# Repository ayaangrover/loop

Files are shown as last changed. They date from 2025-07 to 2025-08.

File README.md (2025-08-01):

<div align="center">

# Loop: Compact MP3 Player

</div>

Loop is a compact MP3 player that's designed to be simple and portable.

loop

## Features

- Can play and store up to 10,000 MP3 files from a microSD card
- 3.5mm TRRS headphone jack
- (Optional) speaker support
- Dual playback support(both headphones and speaker)
- USB-C charging
- 8-10 hours of battery life
- Physical buttons for control
- Custom 3D-printed case (magnet and screw versions)

## Parts List

| Component | Source | Price |
|---|---|---|
| DFPlayer | Amazon | $10.00  |
| TP4056 | AliExpress | $2.00 |
| M2 Screws | Aliexpress | $2.00 |
| M2 Heatset Inserts  | Aliexpress | $2.00 |
| LiPo Battery | Amazon (900mAh) | $8.00 |
| Audio Jack | LCSC | $11.50  |
| Buttons (x3) | LCSC | $0.60 |
| Resistors | LCSC | $1.41 |
| Speaker (x2) | Aliexpress | $1.90 |
| PCB | JLCPCB | $31.00  |
| Case | Printed via Hack Club #printing-legion | Free |
| MicroSD Card | Aliexpress | $3.00 |
| **Total** | — | **$73.41** |

## Enclosure

Designed in Fusion 360. Available in ```./case```.

case

## Firmware

No firmware needed! DFPlayer handles all the playing.

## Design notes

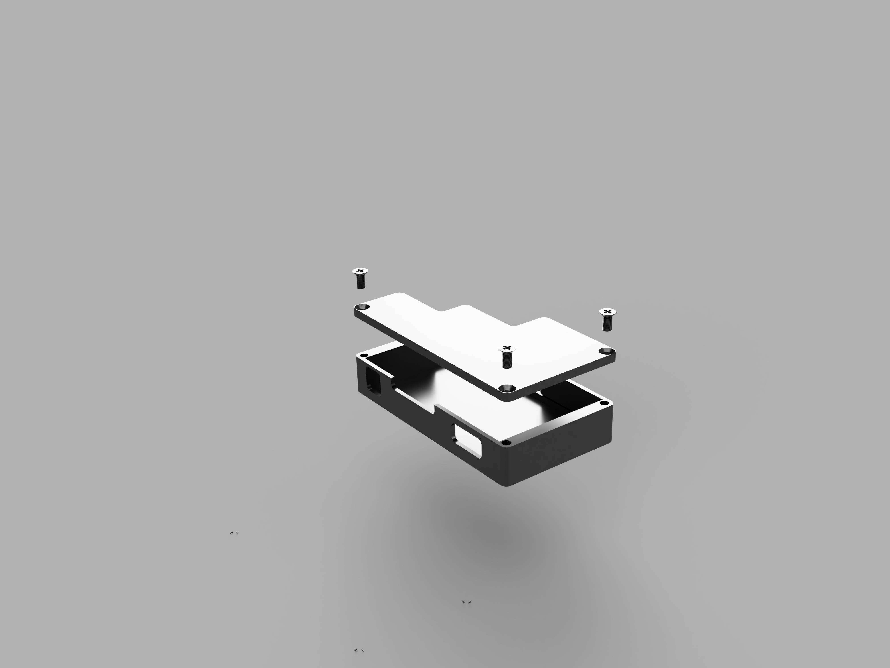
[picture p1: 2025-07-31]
case.png

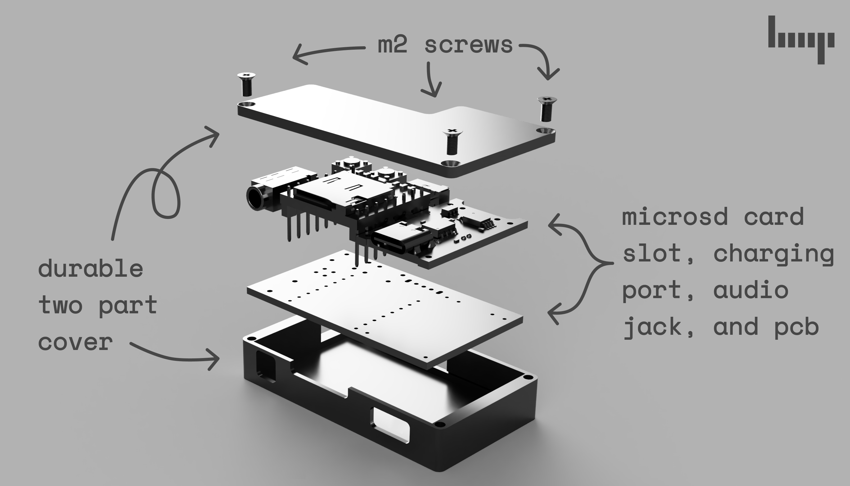
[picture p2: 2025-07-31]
loop.png

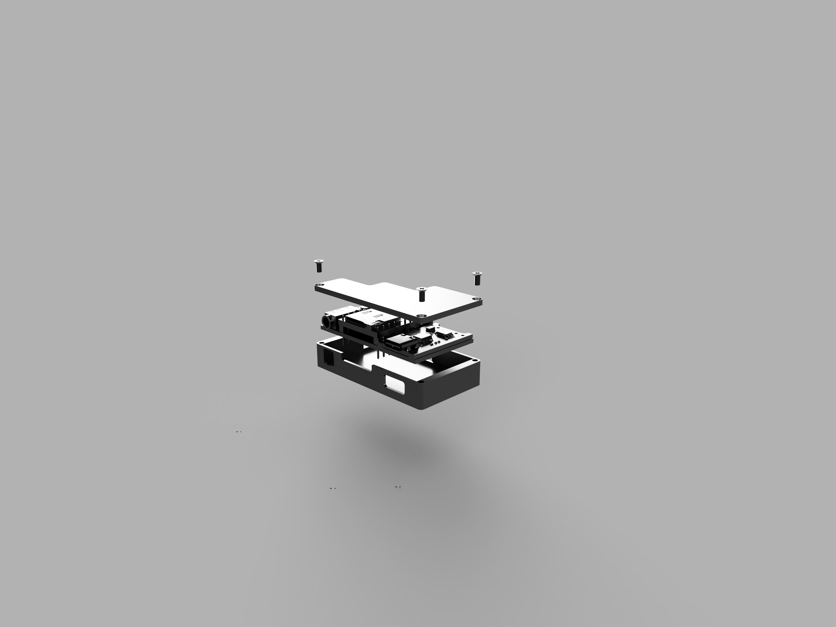
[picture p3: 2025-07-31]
pcb/loop_final.png

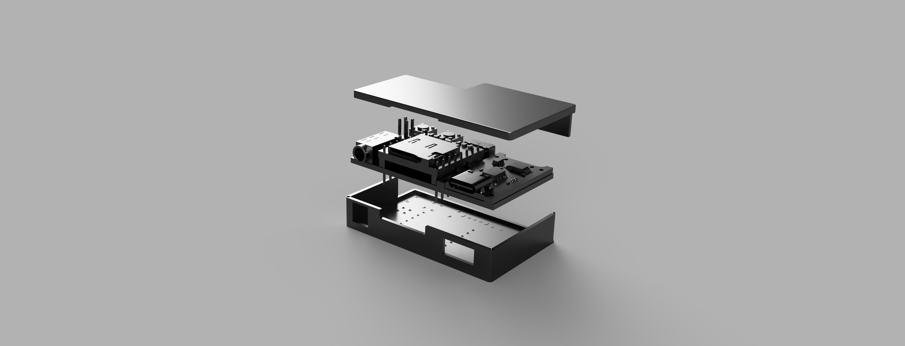
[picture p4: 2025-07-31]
pcb/render.png

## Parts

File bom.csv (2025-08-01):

Component | Source | Price
DFPlayer | Amazon | $10
TP4056 | AliExpress | $2
M2 Screws | Aliexpress | $2
M2 Heatset Inserts | Aliexpress | $2
LiPo Battery | Amazon (900mAh) | $8
Audio Jack | LCSC | $11.50
Buttons (x3) | LCSC | $0.60
Resistors | LCSC | $1.41
Speaker (x2) | Aliexpress | $1.90
PCB | JLCPCB | $31
Case | Printed via Hack Club #printing-legion | Free
MicroSD Card | Aliexpress | $3
Total | N/A | $73.41

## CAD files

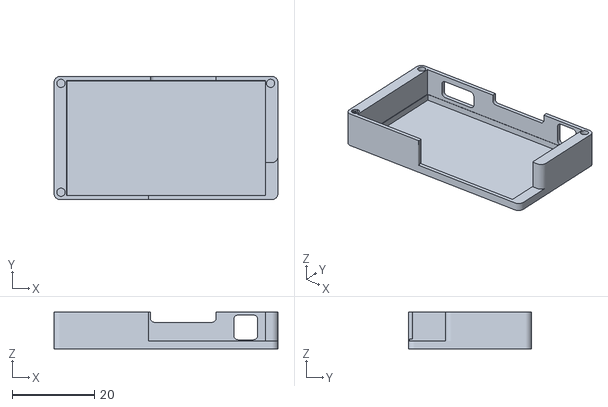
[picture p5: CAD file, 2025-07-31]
case/bottom.stl
54.5 x 30.0 x 9.00

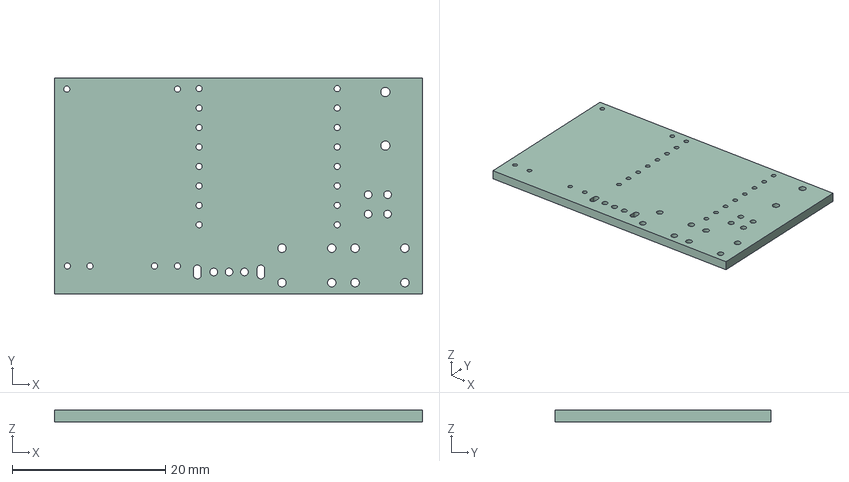
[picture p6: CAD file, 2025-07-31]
pcb/loop2.step
48.0 x 28.2 x 1.51 mm

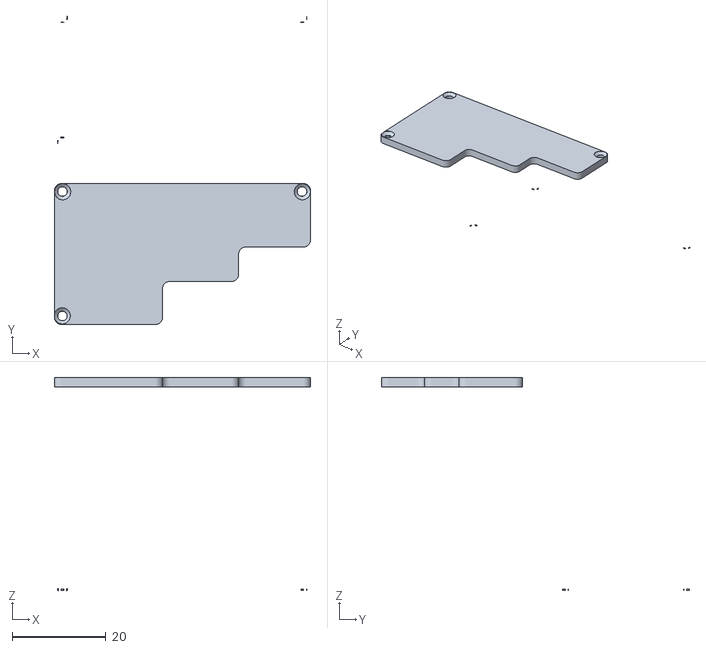
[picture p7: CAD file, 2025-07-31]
case/top.stl
54.5 x 65.6 x 45.4

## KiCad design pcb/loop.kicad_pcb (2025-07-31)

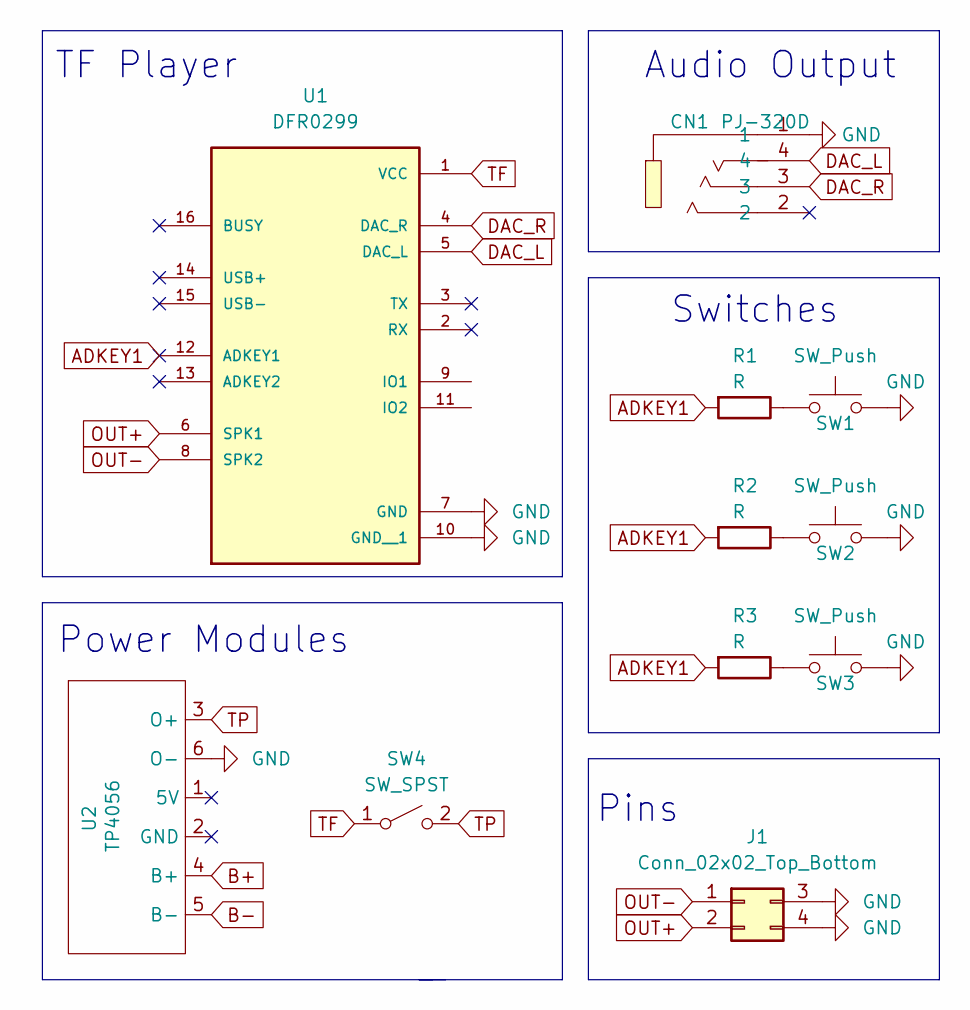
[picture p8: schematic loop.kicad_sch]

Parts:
CN1: PJ-320D; AUDIO-SMD_PJ-320D; LCSC Part C431535
J1: Conn_02x02_Top_Bottom; PinHeader_1x04_P2.00mm_Vertical
R1, R2, R3: R; R_Axial_DIN0207_L6.3mm_D2.5mm_P7.62mm_Horizontal
SW1, SW2, SW3: SW_Push; SW_PUSH_6mm
SW4: SW_SPST; SW-TH_SK12D07VG5
U1: DFR0299; MODULE_DFR0299
U2: TP4056

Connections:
ADKEY1: R1.2, R2.2, R3.2, U1.12 (ADKEY1)
B+: U2.4 (B+)
B-: U2.5 (B-)
DAC_L: CN1.4, U1.5 (DAC_L)
DAC_R: CN1.3, U1.4 (DAC_R)
GND: CN1.1, J1.3, J1.4, SW1.2, SW2.2, SW3.2, U1.7 (GND), U1.10 (GND__1), U2.6 (O-)
unnamed: R1.1, SW1.1
unnamed: R2.1, SW2.1
unnamed: R3.1, SW3.1
OUT+: J1.2, U1.6 (SPK1)
OUT-: J1.1, U1.8 (SPK2)
TF: SW4.1 (A), U1.1 (VCC)
TP: SW4.2 (B), U2.3 (O+)

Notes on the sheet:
Switches
Audio Output
Power Modules
TF Player
Pins

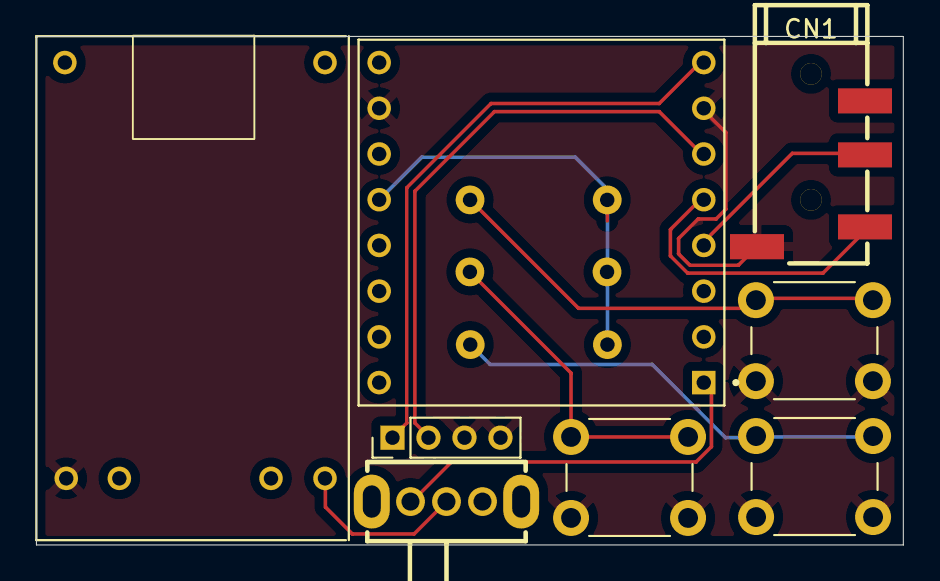
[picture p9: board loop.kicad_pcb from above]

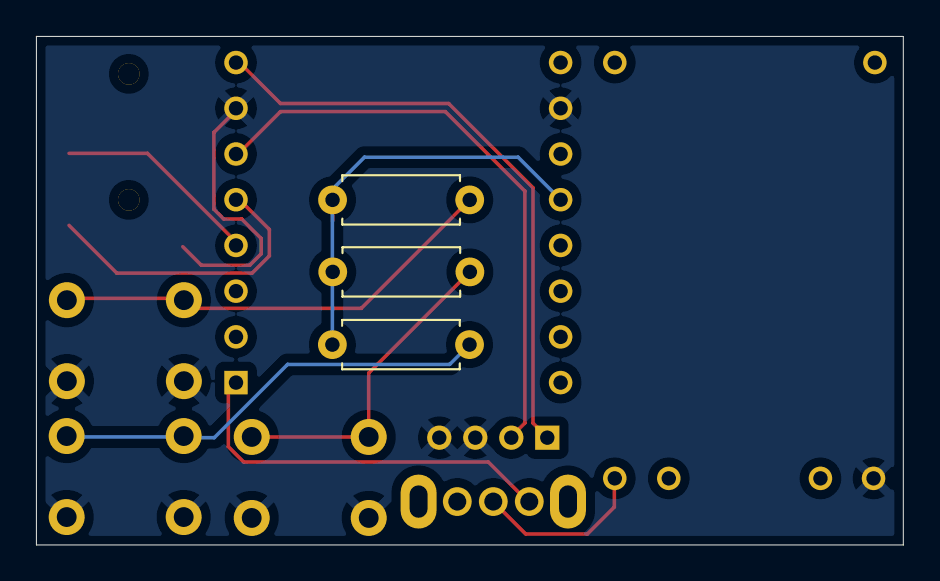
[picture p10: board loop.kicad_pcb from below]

Board: 2 copper layers, 48.2 x 28.2 mm, 11 parts (3 on the bottom side), 11 nets.

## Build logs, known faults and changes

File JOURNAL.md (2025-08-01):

---
title: "Loop"
author: "Ayaan Grover"
description: "Loop is a compact MP3 player that's designed to be simple and portable."
created_at: "2025-07-12"
---

# Journal: Loop - 41 hrs

## July 12, 2025 - 3 hrs
Did a bit of plannning and research today. Here's what i ended up with:

### Parts:
- TF player
- TP4056/similar
- lipo
- audio jack
- maybe a speaker
- buttons
- case
- pcb to hold everything

most parts are cheap and can be sourced from aliexpress if needed. tf player is really good because no mcu is needed, just load the songs on (up to 32gb) and it can play them and skip and stuff.

## July 13, 2025 - 4 hrs
Did a lot of work today. It was very painful to get a lot of the symbols and footprints and i made a couple of my own. also did more research to see if i could make the tf player or tp4056 myself but the costs from PCBA would be too much. 

eventually got everything into kicad(it keeps crashing because i'm on the mac beta). did a basic layout(no wiring yet) and it looks good!

CleanShot 2025-07-13 at 18 38 11

Also made a PR to the highway repo with my project info.

## July 14, 2025 - 3 hrs
Spent a ton of time figuring out the wiring. i have everything except the TRRS jack because the datasheet is really useless...but i did the wiring in the schematic so it technically is working now(i think).

## July 15, 2025 - 2 hrs
spent some time figuring out the TRRS jack, got some help from friends, and i have what i think may be the correct way to do this. it looks right but i'll have to check again later. i also figured out that i'm not going to have an extender for the b+/b- because i dont know what size traces to put and i would rather not mess it up. Also decided to not add spdt a switch for speaker/headphones. i can leave the headphone jack on always and you can add speakers yourself. so i just added a spdt which im using as an spst for the power.



## July 15 - 5 hours
did the layout and wiring and redid it multiple times and now i feel good about it. took so long bc i kept moving stuff around...at least its done now

## July 16 - 4 hrs
made some of the case, used fusion and tinkercad(easier to move stuff and subtract stuff). going to make it look nice later, right now it's just an enclosure. also i didnt add any anchoring points yet.

## July 16 - 5 hrs
redid the case - made the case like a sleeve that you slide onto it for travel and a hook you can close it with, maybe using tpu?

## July 17 - 3 hrs
made a hybrid of the two prev case versions where the sleeve is for the holder for the pcb.

CleanShot 2025-07-31 at 14 47 53@2x

## July 29 - 3 hours
edited the previous version of the case, uses tiny magnets now - its a desk mp3 player so no need for stability. cleaned it up in fusion and made a quick render.

## July 30 - 5 hours
redid the case bc it looked ugly before. now it uses screws instead of magnets and looks better. cleaned it up in fusion

also remade the renders. split the components and the pcb this time so it looks cool. 

also cleaned it up in figma for the readme. now it has a nice cover image. here it is:

loop

also did some budget stuff:

## Parts List

| Component | Source | Price |
|---|---|---|
| DFPlayer | Amazon | $10 |
| TP4056 | AliExpress | $2 |
| M2 Screws | Aliexpress | $2 |
| M2 Heatset Inserts | Aliexpress | $2 |
| LiPo Battery | Amazon (900mAh) | $8 |
| Audio Jack | LCSC | $0.50 + $11 shipping |
| Buttons (x3) | LCSC | $0.60(same shipping as the audio jack) |
| Resistors | LCSC | $1.41(same shipping as the audio jack) |
| Speaker (x2) | Adafruit | $15 |
| PCB | JLCPCB | $31 |
| Case | Printed via Hack Club `#printing-legion` | Free |

**Total: $83.51**

## July 30 - 0.5 hr
made the readme!

## July 30 - 2 hrs
redid the pcb for an extra button using ADKEY1 and 3 resistors. now it has play/pause, next/volup, and prev/voldn.

CleanShot 2025-08-01 at 06 46 19@2x

## July 30 - 1 hr

polished the case and uploaded to github! also made some more renders

case

## July 30 - 0.5 hr

finished and submitted the project!

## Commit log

2025-07-31 Add PCB and Case
    [bottom.stl, loop.kicad_pcb, loop.kicad_sch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]
2025-07-31 update case
